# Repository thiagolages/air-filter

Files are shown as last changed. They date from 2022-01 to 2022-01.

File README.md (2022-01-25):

# air-filter

Python code to be used in a Raspberry Pi to:

  - Check if an air filter inside a vehicle is punctured and is leaking air, which can radically decrease the motor lifespan.
  - Check if the air filter is extremely dirty (saturated) and thus, is making the vehicle consume more fuel.

Freelance project I made with a small company, by demand.

<figure>
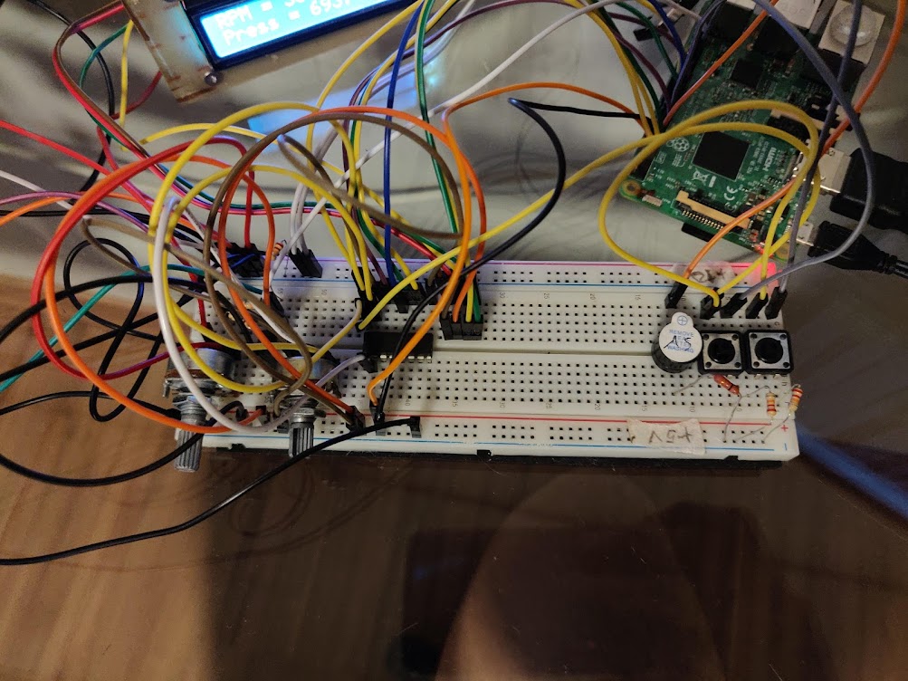
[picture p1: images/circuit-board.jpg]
  
  <figcaption>Fig. 1 - Circuit Board where the experiments were made.</figcaption>  
</figure>

<br/>
<br/>
<br/>

<figure>
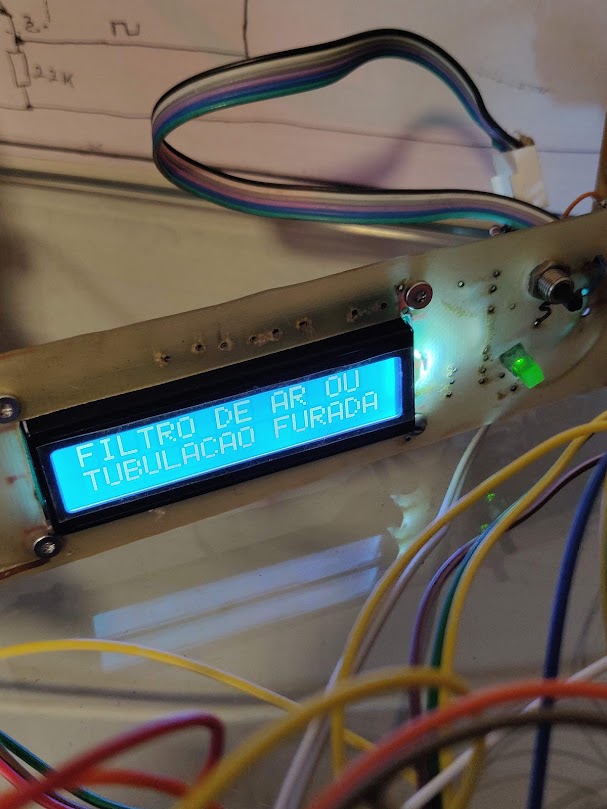
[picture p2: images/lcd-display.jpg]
  
  <figcaption>Fig. 2 - LCD Display used to warn about saturated or punctured filter.</figcaption>  
</figure>

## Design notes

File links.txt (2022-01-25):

GERAL - RASPBERRY PI:

PINOUT:
https://pinout.xyz/pinout/pin15_gpio22

CONVERSOR AD - MCP3008:

BASIC TUTORIALS
https://learn.adafruit.com/raspberry-pi-analog-to-digital-converters/mcp3008
https://www.instructables.com/id/ADC-MCP3008-Raspberry-Pi/

LIBRARY
https://github.com/adafruit/Adafruit_Python_MCP3008

DATASHEET
https://cdn-shop.adafruit.com/datasheets/MCP3008.pdf

LCD

BASIC TUTORIALS
https://learn.adafruit.com/drive-a-16x2-lcd-directly-with-a-raspberry-pi/wiring
https://pimylifeup.com/raspberry-pi-lcd-16x2/

DATASHEET
http://file1.dzsc.com/product/15/01/21/85336_141030602.pdf

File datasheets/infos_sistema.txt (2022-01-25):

1- o circuito utiliza o sensor de pressão MPX 5010 DP, sua faixa de atuação na saida é de 0,2 a 4,7V linear.
]2- O limite de alarme maximo da indicação é 2,25 V, quando atingir este valor , deve  indicar no display FILTRO SATURADO.
E UMA VEZ CORRIGIDO AUTOMATICAMENTE , APAGARA A MENSAGEM DE FILTRO SATURADO E O SISTEMA VOLTARÁ 
LER NORMALMENTE.
Funcionamento geral do sistema 
1-    Sua alimentação será igual ao Raspbery 5VCC.
2-  O raspberry recebera uma amostra de rotação do motor  determinada ( 3200 RPM, 53, hz), capitada pelo  sensor indutivo.Conforme anexo o catalogo com a  saida PNP NA. 
3- Sempre que o motor passar por esta  rotação ele vai memorizar o valor da pressão,  medida pelo sensor MPX5010 ,  quando passar novamente por esta rotação e vlor da pressão
expressa em volts for menor que a medida anterior , é sinal que o filtro esta furado, assim escrever no display FALHA NO FILTRO DE AR OU NA LINHA

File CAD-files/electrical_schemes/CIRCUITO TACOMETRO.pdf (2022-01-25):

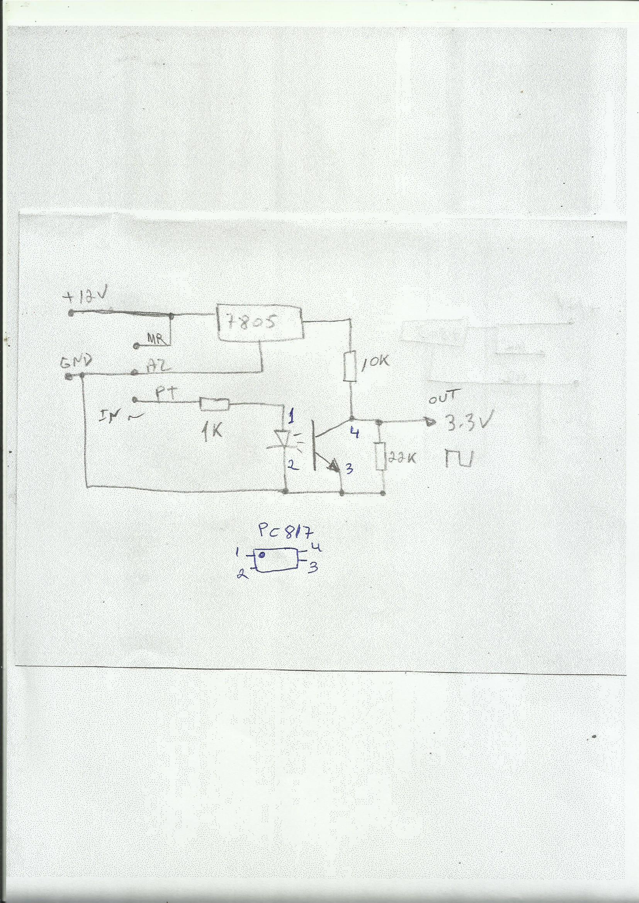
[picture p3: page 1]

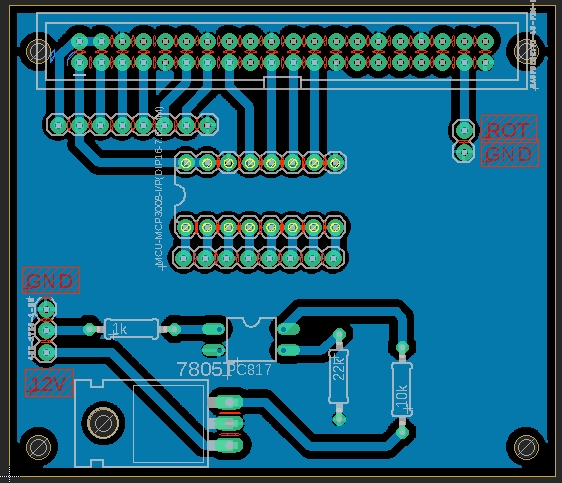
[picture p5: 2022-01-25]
CAD-files/electrical_schemes/FiltroAr-v2.1.jpg

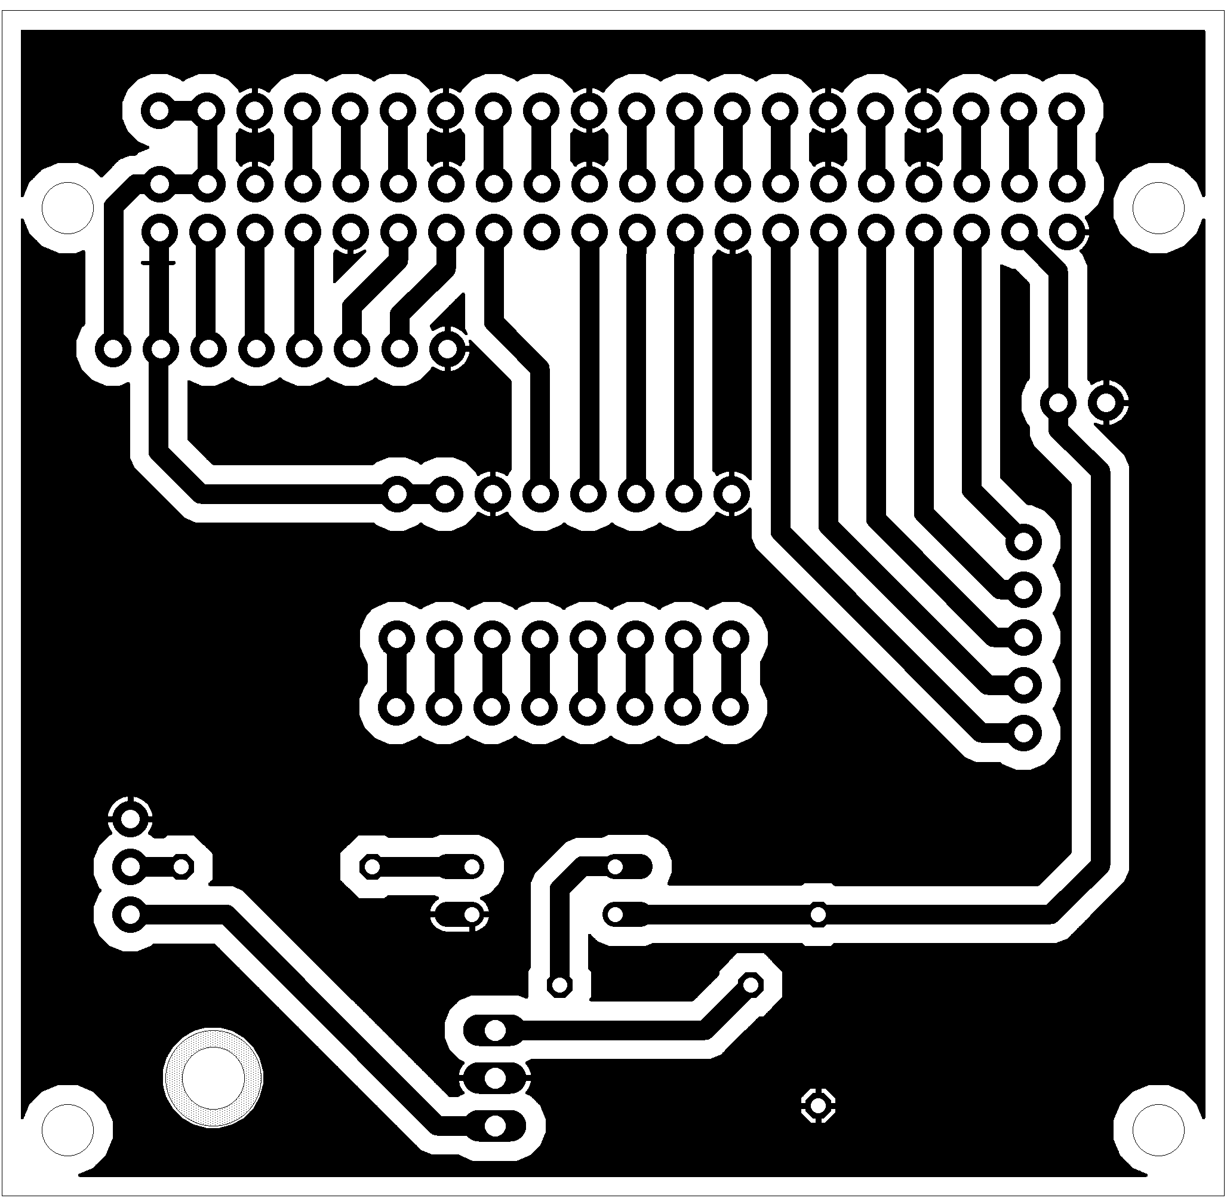
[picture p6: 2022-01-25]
CAD-files/EAGLE/FiltroDeAr-v2.1/filtro_ar-v2-1-bottom.png

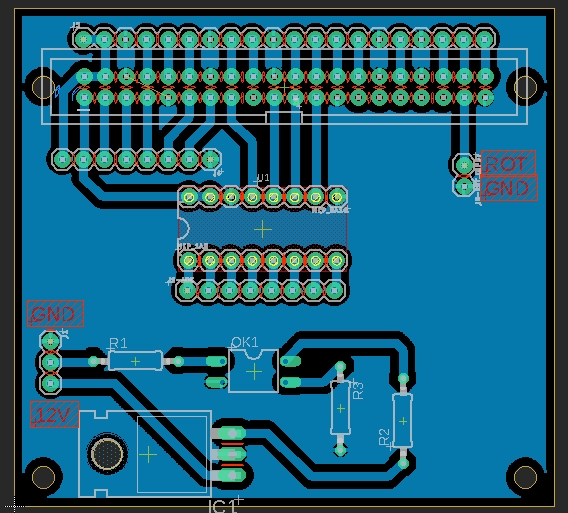
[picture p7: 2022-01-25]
CAD-files/electrical_schemes/FiltroAr-v2.2.jpg

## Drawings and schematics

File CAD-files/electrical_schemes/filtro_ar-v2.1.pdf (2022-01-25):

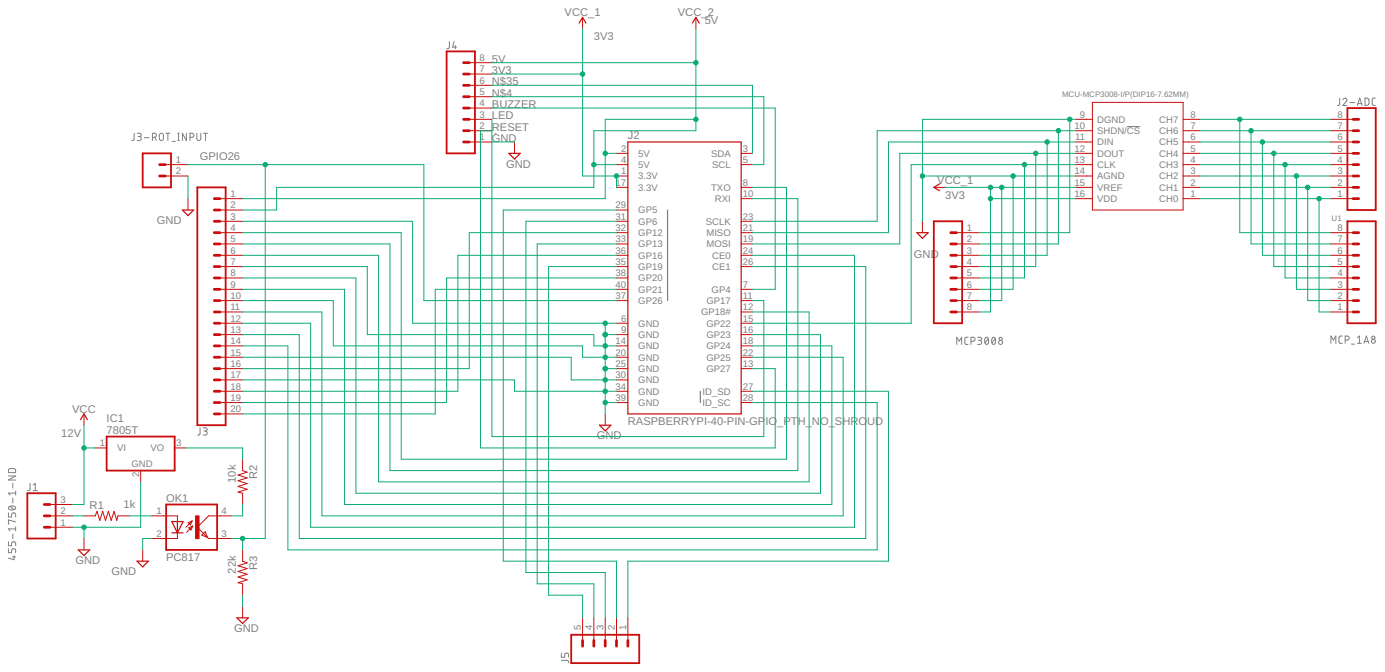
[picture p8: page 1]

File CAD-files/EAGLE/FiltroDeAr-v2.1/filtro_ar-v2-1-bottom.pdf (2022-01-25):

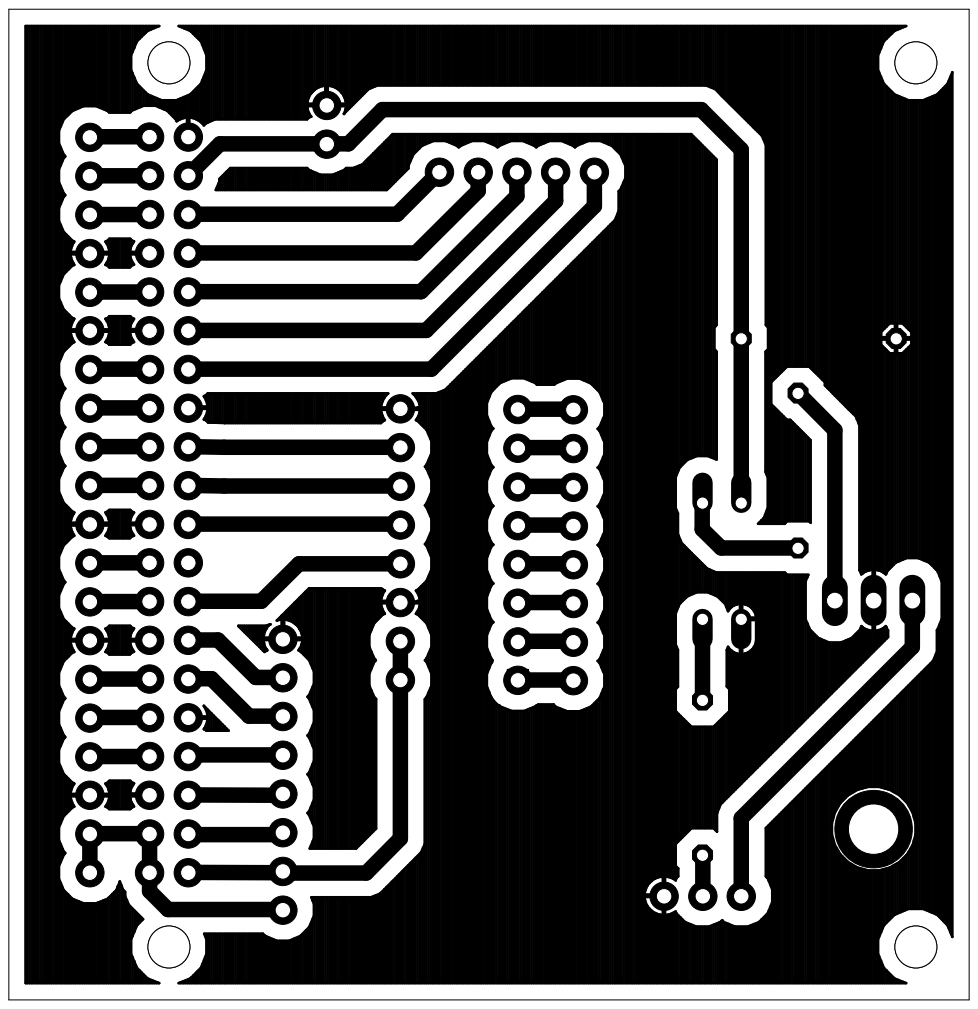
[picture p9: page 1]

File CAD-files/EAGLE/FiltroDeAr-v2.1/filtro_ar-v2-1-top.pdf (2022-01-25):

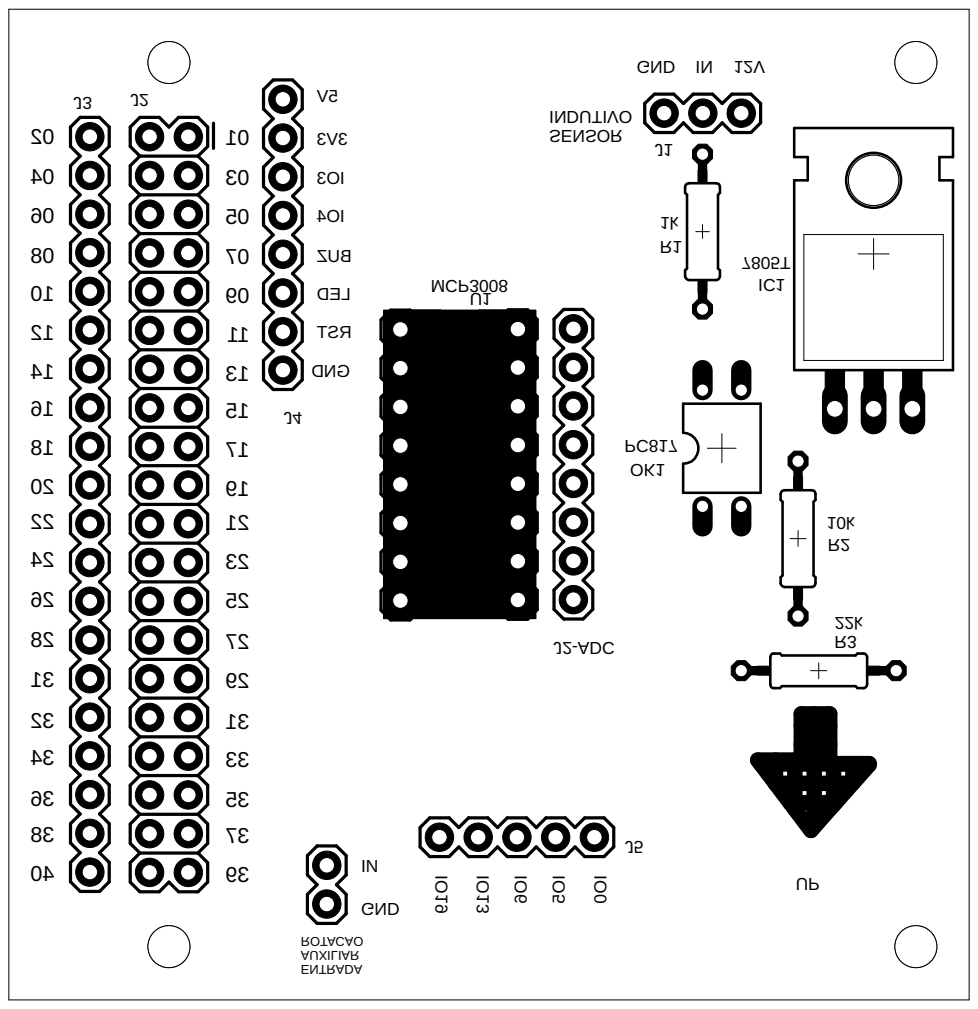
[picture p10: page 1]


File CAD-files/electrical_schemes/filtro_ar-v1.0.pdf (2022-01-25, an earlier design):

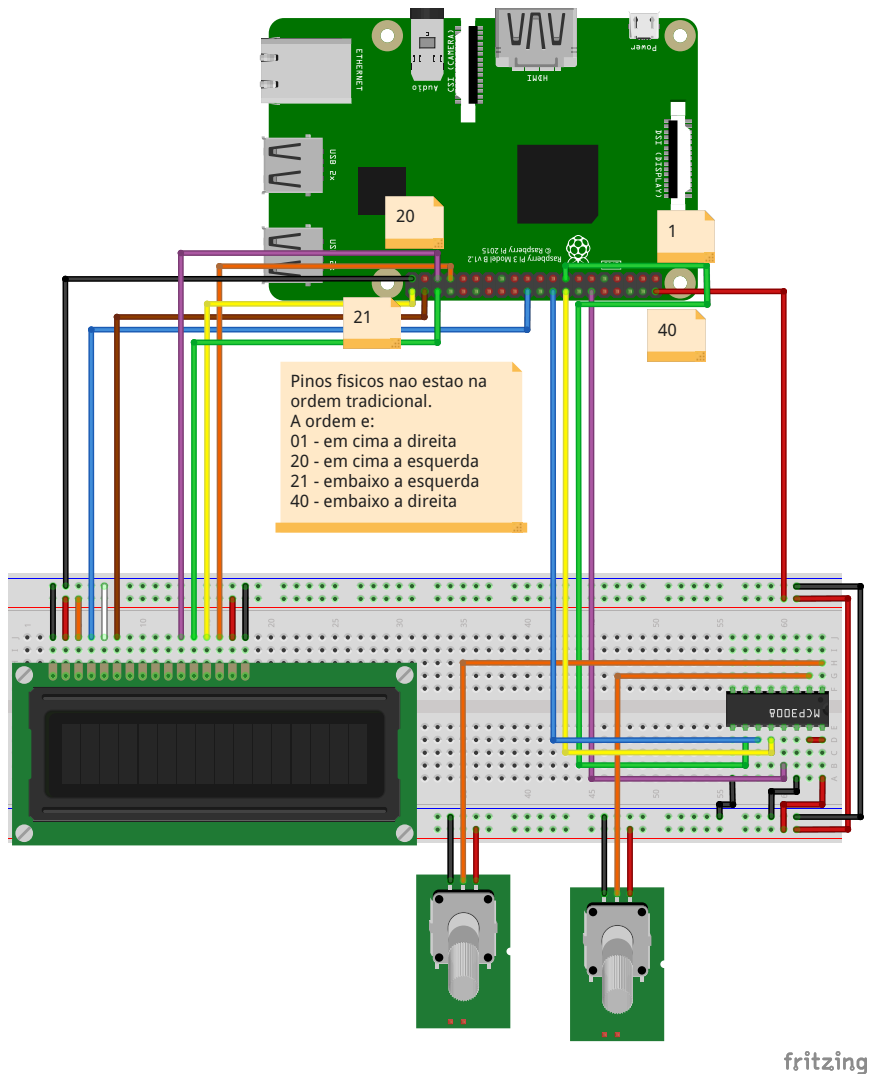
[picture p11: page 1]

Pinos fisicos nao estao na
ordem tradicional.
A ordem e:
01 - em cima a direita
20 - em cima a esquerda
21 - embaixo a esquerda
40 - embaixo a direita

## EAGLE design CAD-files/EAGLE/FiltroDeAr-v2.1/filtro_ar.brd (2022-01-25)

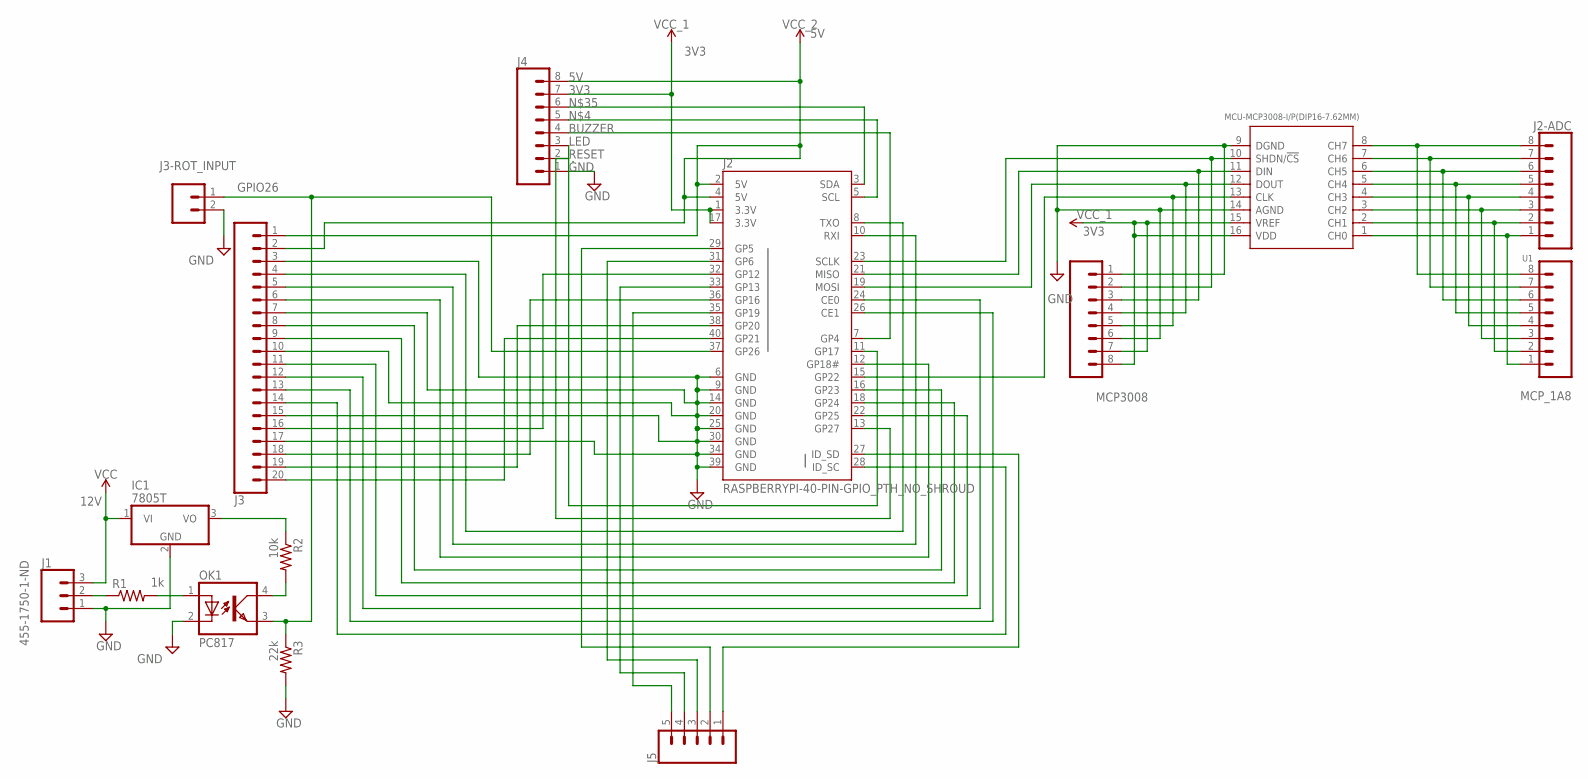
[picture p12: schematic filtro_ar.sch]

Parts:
IC1: 7805T; TO220H
J1: 455-1750-1-ND; 1X03
J2: RASPBERRYPI-40-PIN-GPIO_PTH_NO_SHROUD; 2X20
J2-ADC, J4: CONN_08"; 1X08
J3: CONN_20; 1X20
J3-ROT_INPUT: CONN_02; 1X02
J5: CONN_05; 1X05
MCP3008: CONN_08"; 1X08
MCP_1A8: CONN_08"; 1X08
OK1: PC817; DIL04
R1: 1k; 0207/10
R2: 10k; 0207/10
R3: 22k; 0207/10
U1: MCU-MCP3008-I/P(DIP16-7.62MM); DIP16-2.54-19.2X7.62MM

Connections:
3V3: J2.1 (3.3V), J2.17 (3.3V), J4.7, MCP3008.7, MCP3008.8, U1.15 (VREF), U1.16 (VDD)
5V: J2.2 (5V), J2.4 (5V), J3.1, J3.2, J4.8
12V: IC1.1 (VI), J1.3
BUZZER: J2.7 (GP4), J4.4
GND: IC1.2 (GND), J1.1, J2.6 (GND), J2.9 (GND), J2.14 (GND), J2.20 (GND), J2.25 (GND), J2.30 (GND), J2.34 (GND), J2.39 (GND), J3.3, J3.7, J3.10, J3.15, J3.17, J3-ROT_INPUT.2, J4.1, MCP3008.1, MCP3008.6, OK1.2 (C), R3.2, U1.9 (DGND), U1.14 (AGND)
GPIO26: J2.37 (GP26), J3-ROT_INPUT.1, OK1.3 (EMIT), R3.1
LED: J2.11 (GP17), J4.3
unnamed: J2.23 (SCLK), MCP3008.2, U1.10 (SHDN/!CS)
unnamed: OK1.1 (A), R1.2
unnamed: J2.21 (MISO), MCP3008.3, U1.11 (DIN)
unnamed: J2.5 (SCL), J4.5
unnamed: J2.19 (MOSI), MCP3008.4, U1.12 (DOUT)
unnamed: OK1.4 (COL), R2.2
unnamed: J2.32 (GP12), J3.16
unnamed: J1.2, R1.1
unnamed: IC1.3 (VO), R2.1
unnamed: J2.8 (TXO), J3.4
unnamed: J2.10 (RXI), J3.5
unnamed: J2.12 (GP18#), J3.6
unnamed: J2.16 (GP23), J3.8
unnamed: J2.18 (GP24), J3.9
unnamed: J2.24 (CE0), J3.12
unnamed: J2.15 (GP22), MCP3008.5, U1.13 (CLK)
unnamed: J2-ADC.1, MCP_1A8.1, U1.1 (CH0)
unnamed: J2-ADC.2, MCP_1A8.2, U1.2 (CH1)
unnamed: J2-ADC.3, MCP_1A8.3, U1.3 (CH2)
unnamed: J2-ADC.4, MCP_1A8.4, U1.4 (CH3)
unnamed: J2-ADC.5, MCP_1A8.5, U1.5 (CH4)
unnamed: J2-ADC.6, MCP_1A8.6, U1.6 (CH5)
unnamed: J2-ADC.7, MCP_1A8.7, U1.7 (CH6)
unnamed: J2-ADC.8, MCP_1A8.8, U1.8 (CH7)
unnamed: J2.22 (GP25), J3.11
unnamed: J2.26 (CE1), J3.13
unnamed: J2.28 (ID_SC), J3.14
unnamed: J2.35 (GP19), J5.5
unnamed: J2.27 (ID_SD), J5.1
unnamed: J2.36 (GP16), J3.18
unnamed: J2.38 (GP20), J3.19
unnamed: J2.40 (GP21), J3.20
unnamed: J2.29 (GP5), J5.2
unnamed: J2.3 (SDA), J4.6
unnamed: J2.31 (GP6), J5.3
unnamed: J2.33 (GP13), J5.4
RESET: J2.13 (GP27), J4.2

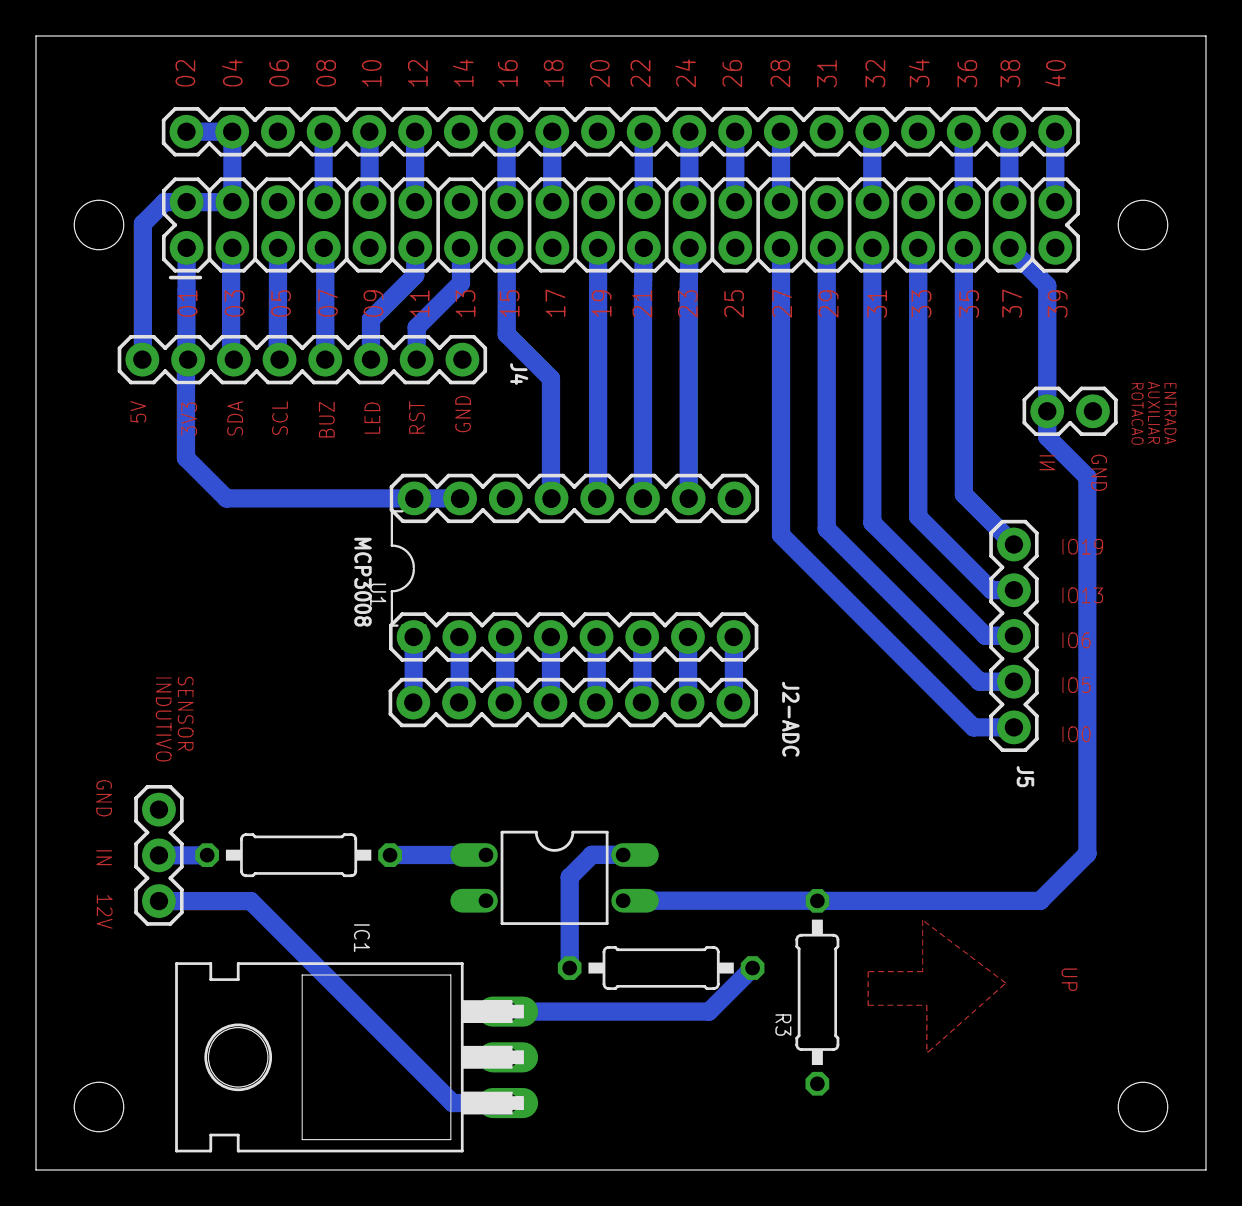
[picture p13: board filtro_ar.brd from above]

Board: 2 copper layers, 65.0 x 63.0 mm, 15 parts (0 on the bottom side), 44 nets.

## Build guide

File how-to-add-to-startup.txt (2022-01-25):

Todos os metodos: https://www.dexterindustries.com/howto/run-a-program-on-your-raspberry-pi-at-startup/

Metodo usado: editar /etc/rc.local

1 - Abrir rc.local:
	sudo nano /etc/rc.local
2 - Adicionar seguinte linha logo antes de 'exit 0' (nao esquecer do &):
	sudo python /PATH/PARA/PROGRAMA/A/SER/EXECUTADO.PY &
3 - Reiniciar o Pi:
	sudo reboot

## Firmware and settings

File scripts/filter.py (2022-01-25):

#!/usr/bin/python
# -*- coding: utf-8 -*-

import RPi.GPIO as GPIO
import numpy as np
import time
import constant # Import file with necessary constants for the program
# ADC
import Adafruit_GPIO.SPI as SPI
import Adafruit_MCP3008
# LCD
import I2C_LCD_driver # to work with the LCD display in I2C mode

# GLOBALS
pressure_array = np.array([-1]) #global because it will be accessed by functions outside main
RPM = 0

# Definitions
						#BEFORE PCB
LED 		= 17 	#6
BOTAO_SLEEP 	= 27	#26
BUZZER 		= 4   	#27
SENSOR_ROTACAO	= 26	#12
BOTAO_RESET 	= 19	# didnt exist

last_time = time.time()
this_time = time.time()

##### LCD #####
lcd = I2C_LCD_driver.lcd()

def setup_GPIOs():

	GPIO.setup(BOTAO_SLEEP	 , GPIO.IN)
	GPIO.setup(BOTAO_RESET	 , GPIO.IN)
	GPIO.setup(SENSOR_ROTACAO, GPIO.IN)

	GPIO.setup(LED 			, GPIO.OUT)
	GPIO.setup(BUZZER 		, GPIO.OUT)

	GPIO.output(BUZZER 	, False)
	GPIO.output(LED 	, False)

# callback that will be called when we detect rising border
def EventsPerTime(GPIO_ENTRADA):
        global RPM, this_time, last_time
        if GPIO.input(GPIO_ENTRADA) > 0.5:
                this_time = time.time()
                RPM = (1/(this_time - last_time))*60 	# in RPM
                #RPM = 1/(this_time - last_time)		# in Hz
                #print ("Current RPM = ",RPM)
                last_time = this_time

##### ADC - MCP3008 ######
# Import SPI library (for hardware SPI) and MCP3008 library.
#import Adafruit_GPIO.SPI as SPI
#import Adafruit_MCP3008

# Software SPI configuration:
		#ANTES DA PCB
CLK  = 22	#18
MISO = 10	#23
MOSI = 9	#24
CS   = 11	#15

mcp = Adafruit_MCP3008.MCP3008(clk=CLK, cs=CS, miso=MISO, mosi=MOSI)


def setup():
	print ("Setting up...")
	#GPIO.setmode(GPIO.BOARD)
	GPIO.setmode(GPIO.BCM)

	setup_GPIOs()

	# to detect rising bordedr and calculate frequency
	GPIO.add_event_detect(SENSOR_ROTACAO, GPIO.RISING, callback=EventsPerTime, bouncetime=1)

	#GPIO.setup(SENSOR_PRESSAO, GPIO.IN)
	#GPIO.setup(SENSOR_ROTACAO, GPIO.IN)	

def rpmToHz(rpm):

	return rpm/60

def getRotation():

	return RPM

def getPressure():
	reading=[0]
	try:
		reading = mcp.read_adc(1)
	except:
		print("erro no MCP")
	#print reading, constant.V_RESOLUTION, constant.FUNDO_DE_ESCALA, constant.VOLTS_POR_MM
	return ((reading*constant.V_RESOLUTION)-constant.FUNDO_DE_ESCALA)/constant.VOLTS_POR_MM #3.3/1023 #/constant.VOLTS_POR_MM

def verifyRotation(r): # will call the two functions below to check in which operating point the motor is
	if (verifyRotationAVG(r) == True):
		return 'AVG'

	elif (verifyRotationMAX(r) == True):
		return 'MAX'

	else:
		pass

def verifyRotationAVG(rotation): # 'average' rotation indicates the point where we check if the filter is punctured
	lower_lim = constant.ROTACAO_AVG*(1-constant.TOLERANCIA_ROTACAO_AVG)
	upper_lim = constant.ROTACAO_AVG*(1+constant.TOLERANCIA_ROTACAO_AVG)
	return (rotation >= lower_lim and rotation <= upper_lim)

def verifyRotationMAX(rotation): # 'maximum' rotation indicates the point where we check if the filter is SATURATED
	lower_lim = constant.ROTACAO_MAX*(1-constant.TOLERANCIA_ROTACAO_MAX)
	upper_lim = constant.ROTACAO_MAX*(1+constant.TOLERANCIA_ROTACAO_MAX)
	return (rotation >= lower_lim and rotation <= upper_lim)

def verifyPressureAVG(p): # tests if the read pressure is lower than the previous, to detect a PUNCTURE
	global pressure_array
#	print("verifyPressureAVG")
	while (estaFurado(p)): # as long as it is PUNCTURED

		printLCD("FILTRO DE AR OU\nTUBULACAO FURADA") # FILTER OR PIPES PUNCTURED
    		print("FILTRO DE AR OU\nTUBULACAO FURADA")# FILTER OR PIPES PUNCTURED
		alarme()
		#EVEN IF THE OPERATOR PRESSES THE BUTTON< WE SHOULD WAIT A FIXED AMOUNT OF TIME TO WARN HIS AGAIN ABOUT PUNCTURED FILTER

		if (GPIO.input(BOTAO_RESET) == True): # In case the RESET button is pressed, indicating that the filter has been changed, we get out of the while() loop
			lcd.lcd_clear()
			GPIO.output(BUZZER      ,False)
                        GPIO.output(LED         ,False)
			pressure_array = np.array([-1])
			break

def verifyPressureMAX(p): # tests if the read pressure is less than the previous ones, to detect SATURATED filter
	global pressure_array
#	print("verifyPressureMAX")
	#print("TESTE")
	#print(constant.LIMIAR_PRESSAO_SATURADO)

	while (estaSaturado(p)): # as long as it is SATURATED
	# it is necessary to obtain new pressure values in a way that, when the filter is cleaned, a values below the threshold is read, and the program follows its execution normally
	#OBS.: the values read during saturation are not kept, and at athe end of this loop, previous stored values are erased, because a new filter will be used
		printLCD("FILTRO SATURADO!")
	    	print("FILTRO SATURADO!")
		alarme()
		# EVEN IF THE OPERATOR PRESSES THE BUTTON, WE SHOULD WAIT A CERTAIN AMOUNT OF TIME TO WARN HIM AGAIN ABOUT THE SATURATED FILTER

		if (GPIO.input(BOTAO_RESET) == True): # In case the RESET button is pressed, indicating the filter has been changed, we get out of the while() loop
                        lcd.lcd_clear()
			GPIO.output(BUZZER      ,False)
                        GPIO.output(LED         ,False)
			pressure_array = np.array([-1])
			break

def alarme(): # routine to ring the alarm and flash the LED
	print("alarme")
	while (GPIO.input(BOTAO_SLEEP) != True or GPIO.input(BOTAO_RESET) != True): # while we dont press the button

	        for i in range(constant.NUM_ALERTAS): # sound and LED
			GPIO.output(BUZZER	,True)
			GPIO.output(LED 	,True)
			time.sleep(constant.TIME_LED_ON)
			GPIO.output(BUZZER 	,False)
		        GPIO.output(LED 	,False)
			time.sleep(constant.TIME_LED_OFF)
			t_now = time.time()

	    	t_prev = time.time()

		while((t_now - t_prev) < constant.TIME_LED_WAIT): # wait some time before sending sound alarm again, but keeps LED flasing
			GPIO.output(LED 	,True)
			time.sleep(constant.TIME_LED_ON)
			GPIO.output(LED 	,False)
			time.sleep(constant.TIME_LED_OFF)
			t_now = time.time()

			if (GPIO.input(BOTAO_RESET) == True): # In case the RESET button is pressed, indicating the filter has been changed, we get out of the while() loop
        	                print("BOTAO RESET ACIONADO !") # RESET BUTTON PRESSED !
				lcd.lcd_clear()
				GPIO.output(BUZZER      ,False)
                        	GPIO.output(LED         ,False)
	                        pressure_array = np.array([-1])
        	                return
			elif(GPIO.input(BOTAO_SLEEP) == True):
				sleep(constant.SLEEP_FILTRO_FURADO)
				return



def sleep(tempo): # snooze time for the filter alarm
	print("sleep")
	sleep_base 	= time.time()
	sleep_now 	= time.time()
	while ((sleep_now - sleep_base) < tempo):
		GPIO.output(LED,True)
		time.sleep(constant.TIME_LED_ON)
        	GPIO.output(LED,False)
		time.sleep(constant.TIME_LED_OFF)
		sleep_now = time.time()
		# update sleep_now
		#if (GPIO.input(BOTAO_SLEEP) == True): # se apertarmos o BOTAO_SLEEP novamente, nao precisamos esperar o tempo completo
		#	break

def estaSaturado(p): # checks if the filter is SATURATED
	#print(constant.LIMIAR_PRESSAO_SATURADO)
	return (p >= constant.LIMIAR_PRESSAO_SATURADO)

def estaFurado(p): # checks if the filter is PUNCTURED
#	print("estaFurado")
	curr_reading = p
	last_reading = pressure_array[-1]
	print("curr = " + str(curr_reading))
	print("last = " + str(last_reading))

 	return (curr_reading < last_reading*(1-constant.TOLERANCIA_PRESSAO_FURADO)) # if the value read is smaller than previous readings

def storePressure(p):
	global pressure_array
#	print("storePressure")
	pressure_array = np.append(pressure_array, p)

	if (pressure_array.size > 1000): # keep only last 1000 readings
		pressure_array = pressure_array[1:1001]
	print ("\nPressao armazenada = "+str(p)+" !\n")
	time.sleep(0.5) # avoid storing many times

def printLCD(x):
	#print("printLCD")
	lcd.lcd_clear()
	if (x.find('\n') != -1): # if there's any line break
		x1, x2 = x.split('\n')
		lcd.lcd_display_string(str(x1), 1)
		lcd.lcd_display_string(str(x2), 2)
	else:
		lcd.lcd_display_string(str(x), 1)
	#time.sleep(1)
if __name__ == "__main__":

	setup()

	try:
		while(True):
			r = getRotation()
			p = getPressure()
			print("Rotacao = "+str(r)+" RPM"),
			print("\tPressao = "+str(p)+"mm H20")
			printLCD("Rotacao = "+str(r)+"\nPressao = "+str(p))
			time.sleep(0.1)
			x = verifyRotation(r)
			# if rotation is 'in the middle' of the scale (motor@1600RPM), and IF we detect a PUNCTURED filter
			if (x == 'AVG'):
				verifyPressureAVG(p)
				# Store read pressure to create a history of readings and check if pressure has lowered
				storePressure(p)
			# if rotation is 'at the end' of the scale (motor@2200RPM) and IF we detect SATURATED filter
			elif (x == 'MAX'):
				verifyPressureMAX(p)

			else:
				pass # do nothing

	except KeyboardInterrupt:
		GPIO.cleanup()
		lcd.lcd_clear()

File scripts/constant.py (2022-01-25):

########### INFOS GERAIS ##########
# -*- coding: utf-8 -*-

VCC = 3.3 # Tensao de referência para o conversor AD, em volts

######## VALORES QUE PODEM SER ALTERADOS ##########

########### PRESSAO #############
PRESSAO_MAXIMA 			= 550	# Em mm de coluna d'agua
TOLERANCIA_PRESSAO_SATURADO 	= 1	# Quantos % da pressao maxima ja devemos considerar filtro SATURADO. Numero de 0 a 1 representando pocentagem! exemplo: 0.9 = 90%
TOLERANCIA_PRESSAO_FURADO 	= 0.10 	# Quantos % abaixo da pressao anterior ja devemos considerar filtro furado. Numero de 0 a 1 representando pocentagem! exemplo: 0.10 = 10%

########### ROTACAO #############
NUM_SENSORES 			= 1 	# Indica quantos objetos por volta serão detectados pelo sensor indutivo de rotacao, em unidades
ROTACAO_AVG_NOMINAL		= 1600 	# Rotacao para verificar filtro FURADO  , em RPM
ROTACAO_MAX_NOMINAL		= 2200 	# Rotacao para verificar filtro SATURADO, em RPM
TOLERANCIA_ROTACAO_AVG_NOMINAL 	= 5	# Numero de 0 a 100, indicando a porcentagem (5%)
TOLERANCIA_ROTACAO_MAX_NOMINAL 	= 5 	# Numero de 0 a 100, indicando a porcentagem (5%)

############ ALARMES ############
NUM_ALERTAS	= 6		# Numero de alertar dados EM SEQUENCIA pelo LED (acendendo e apagando)
TIME_LED_ON  	= 0.1 	# Tempo que o LED ficara ACESO quando estiver em alerta
TIME_LED_OFF 	= 0.1 	# Tempo que o LED ficara APAGADO quando estiver em alerta
TIME_LED_WAIT	= 5		# Tempo que o LED ficara EM REPOUSO, após alertar NUM_ALERTAS vezes

# Tempo de 'soneca' dos alarmes (EM SEGUNDOS)
SLEEP_FILTRO_SATURADO 	= 30 # Tempo de descanso no alarme sonoro, depois de o operador apertar o botao de SLEEP, em segundos
SLEEP_FILTRO_FURADO	= 10 # Tempo de descanso no alarme sonoro, depois de o operador apertar o botao de SLEEP, em segundos

#####################################################################
#####################################################################
################### NAO MUDE NADA DAQUI PRA BAIXO ###################
#####################################################################
#####################################################################


RESOLUTION 	= 2**10 		# 1024 valores (10 bits)
V_RESOLUTION 	= VCC/RESOLUTION 	# Resolucao em volts = VCC/(resolucao)


#################### ROTACAO ####################
###### AVG - Para medicao de FILTRO FURADO ######
ROTACAO_AVG 		= NUM_SENSORES*ROTACAO_AVG_NOMINAL # Rotacao final obtida, em RPM
TOLERANCIA_ROTACAO_AVG 	= TOLERANCIA_ROTACAO_AVG_NOMINAL/100.

##### MAX - Para medicao de FILTRO SATURADO #####
ROTACAO_MAX 		= NUM_SENSORES*ROTACAO_MAX_NOMINAL # Rotacao final obtida, em RPM
TOLERANCIA_ROTACAO_MAX 	= TOLERANCIA_ROTACAO_MAX_NOMINAL/100.


#################### PRESSAO ####################
P_MIN_SENSOR    = 0             #mm H20
P_MAX_SENSOR    = 1019.78       #mm H20
V_MIN_SENSOR    = 0.2           # Volts
V_MAX_SENSOR    = 4.7           # Volts
FUNDO_DE_ESCALA = 0.237		# Volts

VOLTS_POR_MM    = (V_MAX_SENSOR - V_MIN_SENSOR)/(P_MAX_SENSOR - P_MIN_SENSOR)
#VOLTS_POR_MM			= 0.004412716

P_MAX_IN_V 			= PRESSAO_MAXIMA*VOLTS_POR_MM # correspondente a 500mm, 2.23V # em volts - definido por experimentacao (metade da escala)

P_MAX				= (P_MAX_IN_V-FUNDO_DE_ESCALA)*(RESOLUTION-1)/VCC # pressao maxima em numeros inteiros do ADC
LIMIAR_PRESSAO_SATURADO		= TOLERANCIA_PRESSAO_SATURADO*PRESSAO_MAXIMA

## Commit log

2022-01-25 Add electrical schemes
    [filtro_ar-v1.0.fzz, filtro_ar.fzz]
2022-01-25 Add EAGLE CAD design files
    [filtro_ar.brd, filtro_ar.sch]

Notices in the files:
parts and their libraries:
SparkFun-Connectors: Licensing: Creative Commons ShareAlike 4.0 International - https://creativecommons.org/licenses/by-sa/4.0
